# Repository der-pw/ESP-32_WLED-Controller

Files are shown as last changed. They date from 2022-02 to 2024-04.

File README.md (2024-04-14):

# ESP-32_WLED-Controller  

[deutsche Version unten ->](#Deutsch)

### tl;dr
let's talk about [maximum ratings](./maximum_ratings.md)

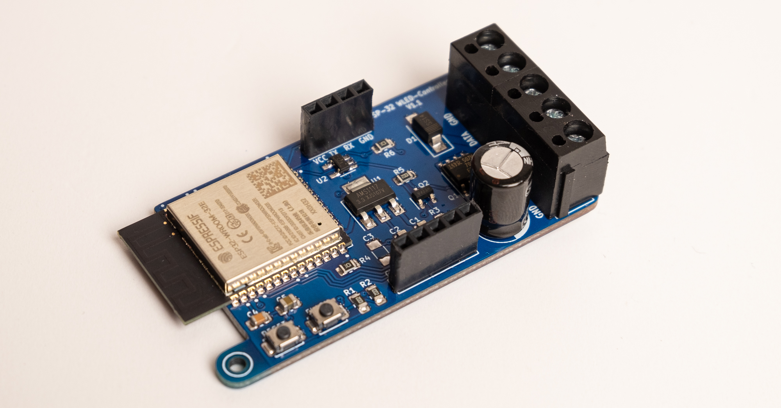
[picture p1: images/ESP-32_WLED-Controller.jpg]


This is like an evolution of my [ESP-12-WLED_Controller](https://github.com/der-pw/ESP-12_WLED-Controller). It based on my ESP-12 Controller, so you can find also all the necessary information about MOSFETs, etc. there as well.

The version with ESP32 is more powerful and enables features like Sound Reactive https://github.com/atuline/WLED with significantly better performance than the ESP2866. Also you can find here the [Sound Reactive Addon](ESP-32_WLED-Controller_Addon) for this controller. The PCB size has just slightly increased, and the controller can still fit into small projects. To have a clean design and ensure the LED strip works with a 5V data level, I used a 74LVC1G125 as a Logic Level Shifter.

Additionally, the power supply for the LED strip can be turned off by using a P-channel MOSFET. Even when turned off, NEOPIXEL strips consume some power (approximately 1mA per pixel). Luckily, WLED provides an option to control a "Relay" through a user-defined pin. I use an IRF7410 (MOSFET P-channel -12 V -16A SO-8) which can switch max 16A. Additional to the P-MOSFET, there is another N-MOSFET. It works as a driver to switch the P-MOSFET with a 5V logic level and also as an inverter, allowing the main MOSFET to logical "active HIGH" at GPIO12 of the ESP.

## Settings
The configuration for inputs and outputs is as follows:

Label | GPIO | Remarks
--- | --- | ---
Data Pin | `GPIO 2`  
Relay Pin | `GPIO12` | **invert**  
*optional:*  
Button 0 | `GPIO32`  
Button 1 | `GPIO33`  
ADC | `GPIO36` | Analog Input

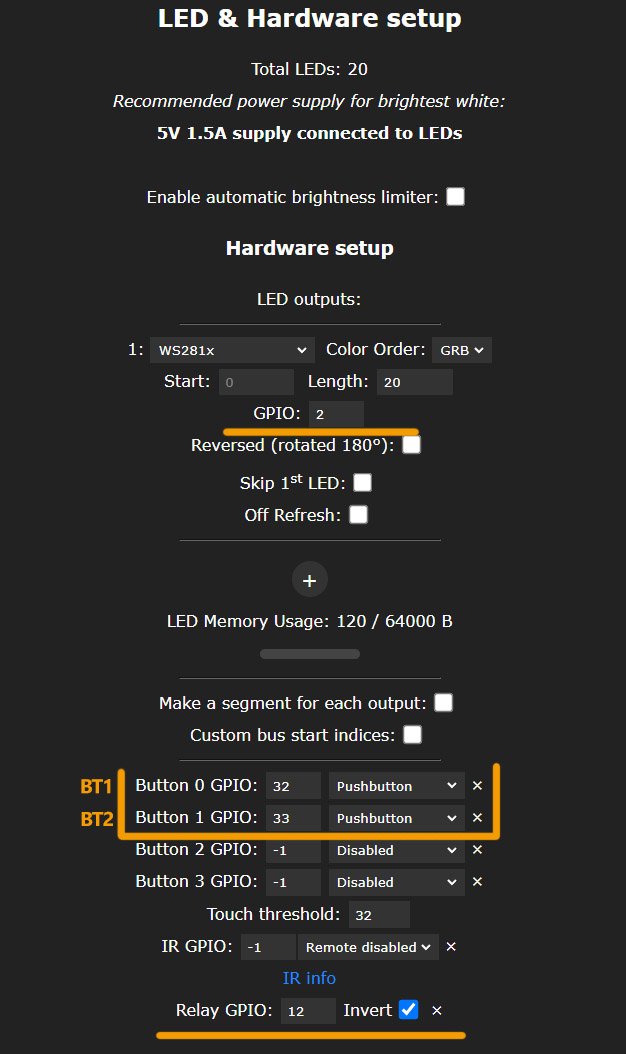
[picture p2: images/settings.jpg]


## Flashing the Firmware
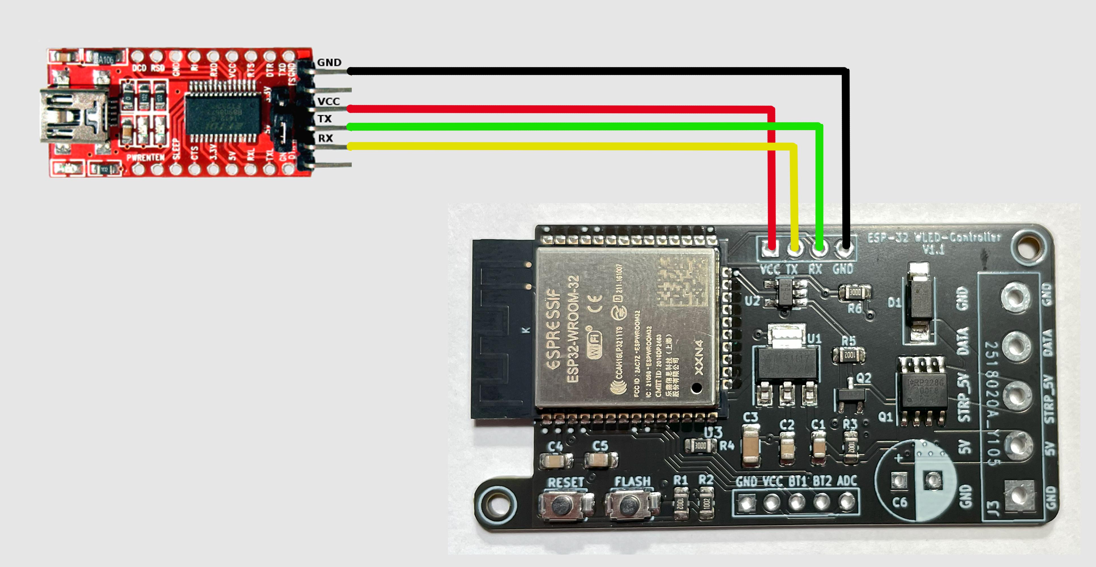
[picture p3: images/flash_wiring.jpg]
Flash Wiring


Connect an FTDI or another compatible UART converter like showing the wiring diagram. Either connect with the FLASH button pressed or, if the controller is already powered by a power supply, hold FLASH, press RESET briefly, and then release FLASH. Now controller is in bootloader mode.

The ESP32 may be underpowered by the FTDI, causing the Brownout Detection is triggered. Therefore, you need to power the controller with an external 5V voltage source.

This controller can be used with a [pre-made binary](https://install.wled.me/).

## Strip and Power Supply
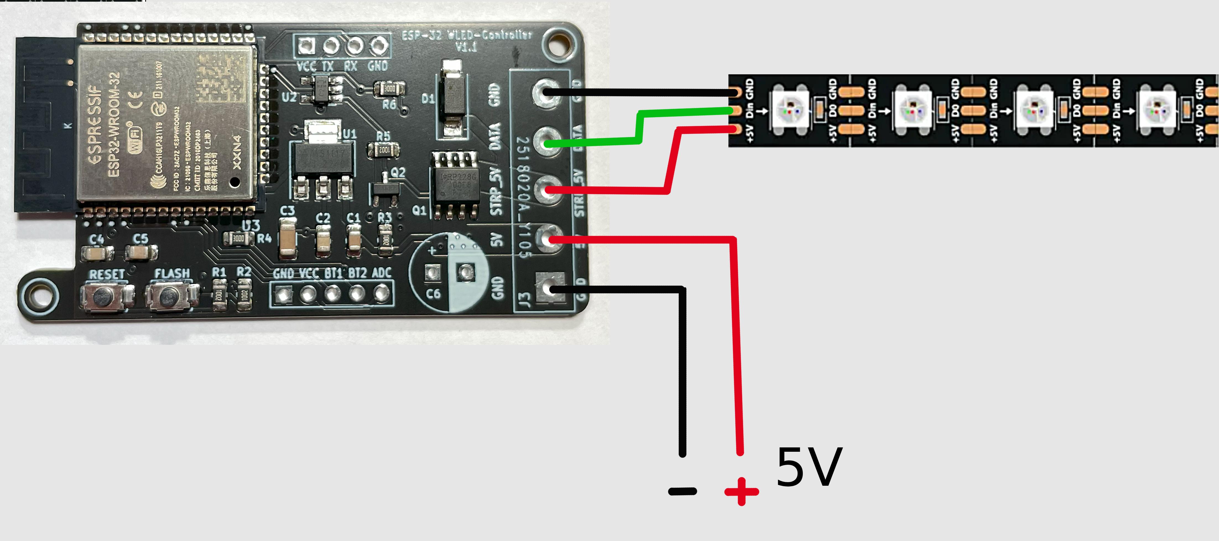
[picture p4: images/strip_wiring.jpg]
Strip and Power Supply


Connect the LED strip and power supply as per the wiring diagram.

## Parts List and BOM
| Designator | Footprint | Quantity | Value | Info |
|---|---|----|----|----|
| C1, C5 | 0805 | 2 | 10µF | |
| C2 | 0805 | 1 | 47µF | |
| C3 | 1206 | 1 | 100µF | |
| C4 | 0805 | 1 | 100nF | |
| D1 | D_SMA_Handsoldering | 1 | Flyback diode| |
| Q1 | SOIC-8_3.9x4.9mm_P1.27mm | 1 | IRF7410 | |
| Q2 | SOT-23 | 1 | IRLML6344 | |
| R1, R2, R3, R5| 0805 | 4 | 10k | |
| R4, R6 | 0805 | 2 | 300R | |
| SW1 | SW_Push_SPST_NO_Alps_SKRK_handsolder | 1 | Reset | |
| SW2 | SW_Push_SPST_NO_Alps_SKRK_handsolder | 1 | Flash | |
| U1 | SOT-223-3_TabPin2 | 1 | AMS1117-3.3  | |
| U2 | SOT-23-5_HandSoldering | 1 | 74LVC1G125 | |
| U3 | ESP32-WROOM-32 | 1 | ESP32-WROOM-32| |

Includes parts that need to be soldered by hand.

Quantity | Description | Info
-------- | -------- | --------
1   | CTB1202-5BK   | [Solderable Screw Terminal - 5-pin, Pitch 5 mm](https://www.reichelt.de/loetbare-schraubklemme-5-pol-rm-5-mm-90--ctb1202-5bk-p292662.html)
1   | NHG-A 1.0M 6.3   | [Capacitor, radial, 1000µF, 6.3V, Pitch 3.5mm](https://www.reichelt.de/elko-radial-1-000-f-6-3v-rm3-5-1000h-105-c-20--nhg-a-1-0m-6-3-p200391.html)

## Case
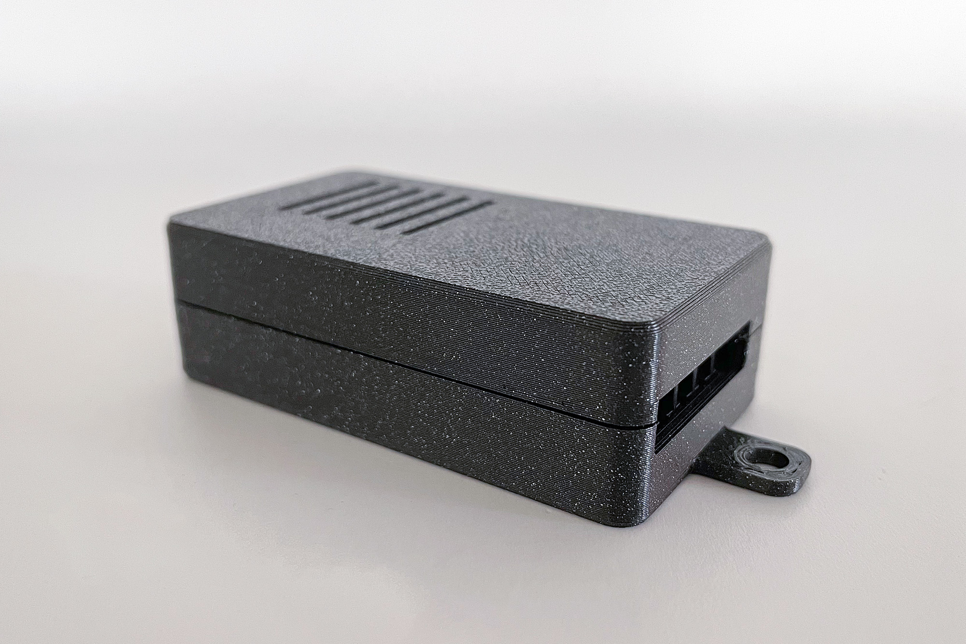
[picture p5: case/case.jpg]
Case
  

There is also a simple case available. Both parts can be connected with a click fastener. The STEP file for modifications to the case is included in the project folder.

## Gerbers
You can find the necessary fabrication data in the “gerber” folder. This also includes the BOM and CPL files. I have had good experiences with JLCPCB, and production there ran smoothly with the data. However, some parts may not always be available.

## Thank You!
A special thanks to [Aircoookie](https://github.com/Aircoookie) and all those involved in the [WLED](https://github.com/Aircoookie/WLED) project!  
Gerber and fabrication data were created using the [Fabrication Toolkit](https://github.com/bennymeg/JLC-Plugin-for-KiCad).



---
## Deutsch
PCB-top_3D-Modell

Dies ist die Weiterentwicklung meines [ESP-12-WLED_Controllers](https://github.com/der-pw/ESP-12_WLED-Controller). Daher kannst du alle nötigen Infos über MOSFET etc. auch dort finden.  
Die Version mit ESP32 ist leistungfähiger und ermöglicht bswp. Sound Reactive Features https://github.com/atuline/WLED. Dafür findes du auch hier ein [Sound Reactive Addon](ESP-32_WLED-Controller_Addon), welches einfach auf den Controller gesteckt werden kann. Die Platinengröße ist nur minimal gewachsen, der Controller lässt sich nach wie vor in kleinen Projekten unterbringen. Für ein sauberes Design und damit der LED-Strip mit einem 5V Datenpegel arbeitet verwende ich einen 74LVC1G125 als Logic Level Shifter.  
Zusätzlich kann die Versorgungsspannung für den LED-Strip über einen P-Kanal MOSFET abgeschaltet werden. Auch im ausgeschalteten Zustand verbrauchen die NEOPIXEL-Strips nämlich Strom (ca. 1mA/Pixel). Ich verwende einen IRF7410 (MOSFET P-Kanal -12 V -16A SO-8) dieser kann max 16A schalten.
Praktischerweise bietet WLED hier die Möglichkeit über einen frei definierten Pin ein "Relay" zu schalten. Vor dem P-MOSFET sitzt ein weiterer N-MOSFET. Einmal funktioniert dieser als Treiber um den P-MOSFET mit 5V Logikpegel zu schalten und zum anderen als Inverter, damit der Haupt-MOSFET praktisch "active HIGH" am GPIO12 des ESP durchschaltet. 

## Einstellungen
Die Konfiguration für Ein-/ und Ausgänge erfolgt wie abgebildet.  

Bezeichnung | GPIO | Bemerkung
--- | --- | ---
Data Pin | `GPIO 2`  
Relay Pin | `GPIO12` | **invert**  
*optional:*  
Button 0 | `GPIO32`  
Button 1 | `GPIO33`  
ADC | `GPIO36` | Analog Eingang

PCB-top_3D-Modell  

## Firmware flashen
Flash Wiring  

FTDI oder anderen passenden UART-Wandler gemäß Anschlussplan verbinden.
Entweder mit gedrücktem FLASH Button verbinden oder wenn der Controller bereits über ein Netzteil versorgt wirden, FLASH gedrückt halten, RESET kurz drücken und danach kann FLASH losgelassen werden.  

Möglicherweise wird der ESP32 vom FTDI unterversorgt und die Brownout Detection reagiert. Daher ist es ratsam, den Controller bereits mit einer externen 5V Spannungsquelle zu versorgen.  

Dieser Controller kann mit einem [fertigen Binary](https://install.wled.me/) verwendet werden.

## Strip und Versorgungsspannung
Strip and Power Supply  
LED Strip und Netzteil werden gemäß Anschlussplan verbunden.

## Teileliste und BOM
| Designator | Footprint | Quantity | Value | Info |
|---|---|----|----|----|
| C1, C5 | 0805 | 2 | 10µF | |
| C2 | 0805 | 1 | 47µF | |
| C3 | 1206 | 1 | 100µF | |
| C4 | 0805 | 1 | 100nF | |
| D1 | D_SMA_Handsoldering | 1 | Flyback diode| |
| Q1 | SOIC-8_3.9x4.9mm_P1.27mm | 1 | IRF7410 | |
| Q2 | SOT-23 | 1 | IRLML6344 | |
| R1, R2, R3, R5| 0805 | 4 | 10k | |
| R4, R6 | 0805 | 2 | 300R | |
| SW1 | SW_Push_SPST_NO_Alps_SKRK_handsolder | 1 | Reset | |
| SW2 | SW_Push_SPST_NO_Alps_SKRK_handsolder | 1 | Flash | |
| U1 | SOT-223-3_TabPin2 | 1 | AMS1117-3.3  | |
| U2 | SOT-23-5_HandSoldering | 1 | 74LVC1G125 | |
| U3 | ESP32-WROOM-32 | 1 | ESP32-WROOM-32| |

Beinhaltet Teile, die von Hand eingelötet werden müssen.
Anzahl | Beschreibung | Info
-------- | -------- | --------
1   | CTB1202-5BK   | [Lötbare Schraubklemme - 5-pol, RM 5 mm](https://www.reichelt.de/loetbare-schraubklemme-5-pol-rm-5-mm-90--ctb1202-5bk-p292662.html)
1   | NHG-A 1,0M 6,3   | [Elko, radial, 1.000µF, 6,3V, RM3,5](https://www.reichelt.de/elko-radial-1-000-f-6-3v-rm3-5-1000h-105-c-20--nhg-a-1-0m-6-3-p200391.html)

## Gehäuse
Gehäuse  

Ein einfaches Gehäuse gibt es auch.
Beide Teile können über einen Klickverschluss miteinander verbunden werden.
Für Änderungen am Gehäuse liegt im Projektorder die STEP-Datei.  

## Gerberdaten
Du kann die nötigen Fertigungsdaten im Ordner "gerber" finden. Darin enthalten sind auch die BOM und CPL Files. Mit JLCPCB habe ich guter Erfahrungen gemacht, und mit den Daten lief die Fertigung dort auch problemlos. Es ist jedoch möglich, das manche Teile vielleicht nicht immer verfügbar sind.

## Dankeschön!  
Ganz besonderer Dank geht an [Aircoookie](https://github.com/Aircoookie) und alle Beteiligten, die am [WLED](https://github.com/Aircoookie/WLED) Projekt mitarbeiten!  
Gerber und Fertigungsdaten wurden mit [Fabrication Toolkit](https://github.com/bennymeg/JLC-Plugin-for-KiCad) erstellt!



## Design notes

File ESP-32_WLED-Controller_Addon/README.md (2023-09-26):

# ESP-32_WLED-Controller_addon  

[deutsche Version unten ->](#Deutsch)

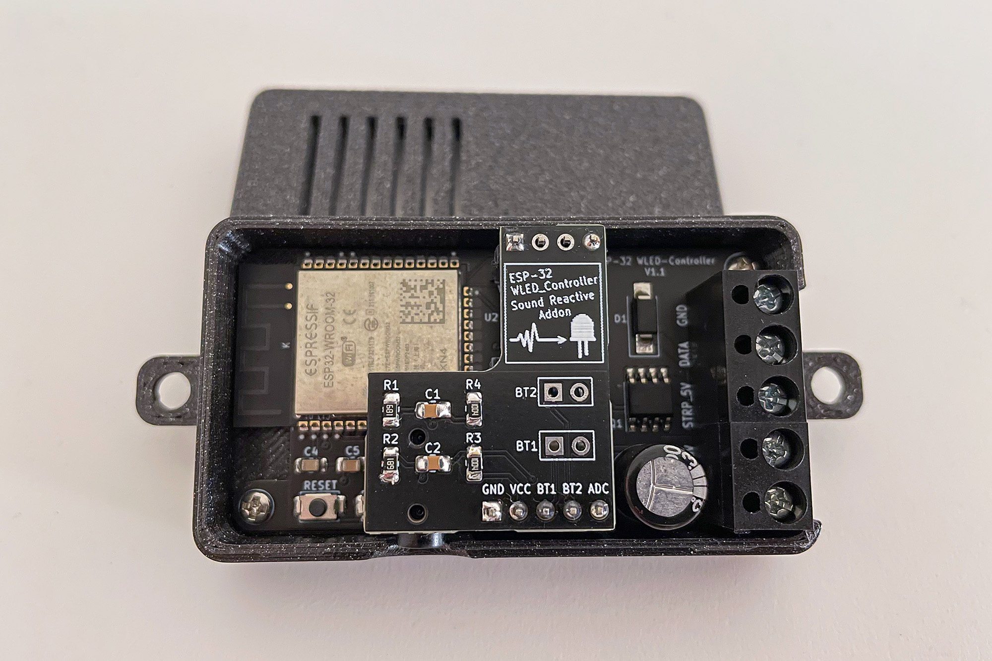
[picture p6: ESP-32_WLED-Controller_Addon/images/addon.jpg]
PCB-top_addon


This addon board allows you to expand the ESP-32_WLED-Controller with the Sound Reactive feature https://github.com/atuline/WLED. The board is practically stacked on top of the controller using 2.54mm pin and socket headers.

## Settings
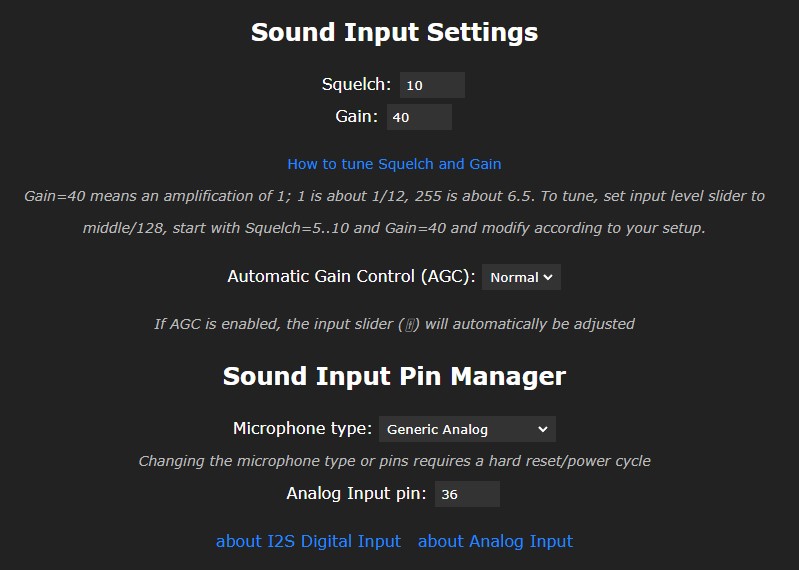
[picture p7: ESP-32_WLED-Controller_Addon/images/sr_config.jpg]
Settings


WLED Sound Reactive comes with an additional configuration menu.
For Squelch and Gain, you'll need to configure your own settings.
Microphone type is **Generic Analog**.
The Analog Input Pin is on `GPIO36`.

## Case
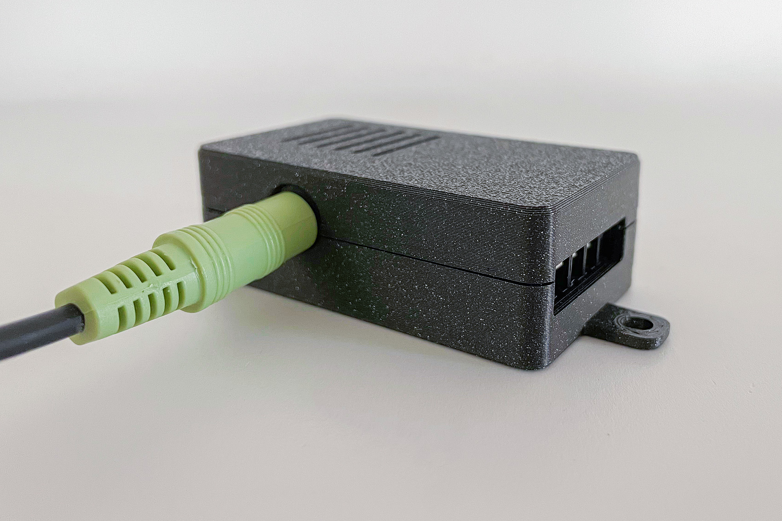
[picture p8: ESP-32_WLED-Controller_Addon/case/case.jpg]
case


There is also a simple case available for connecting the 3.5mm audio jack.
The STEP file for further modifications is also located in the "case" folder.

## BOM

| Refs | Qty | Component | Description |
| --- | --- | --- | --- |
| R1, R2 | 2 | 680R | Resistor 0805  |
| R3, R4 | 2 | 1M | Resistor 0805  |
| C1, C2 | 2 | 100nF | Capacitor 0805  |
| J3 | 1 | Audio Jack 3.5mm | PJ230D https://de.aliexpress.com/item/4000661908135.html |
| J1 | 1 | PinHeader_1x05_P2.54mm_Vertical |
| J5 | 1 | PinHeader_1x04_P2.54mm_Vertical |

## Gerber Data

You can find the manufacturing data for the board in the “gerber” folder.
In addition, there is also the BOM and CPL data for SMT production. However, the assembly is two-sided, as the jack socket is mounted on the bottom for space reasons.
The jack socket is called PJ230D. I found these cheaply at https://de.aliexpress.com/item/4000661908135.html.

---
## Deutsch

PCB-top_addon

Mit dieser Addon-Platine lässt sich der ESP-32_WLED-Controller um das Sound Reactive Feature erweitern https://github.com/atuline/WLED. Die Platine wird praktisch im "Huckepack" auf den Controller gesteckt.
Dazu lassen sich 2.54mm Stift- und Buchsenleisten verwenden.

## Einstellungen
Einstellungen

WLED Soundreactive hat ein weiteres Konfigurationsmenü.
Für Squelch und Gain muss man seine eigenen Einstellungen fingen.
Micropone type ist **Generic Analog**.  
Der Analog Input Pin liegt auf `GPIO36`.

## Gehäuse
case

Es gibt auch ein einfaches Gehäuse, damit man den 3,5mm Klinkenstecker anschließen kann.
Die STEP-Datei für weitere Modifikationen befindet sich auch in dem Ordner "case" 

## BOM

| Refs | Qty | Component | Description |
| --- | --- | --- | --- |
| R1, R2 | 2 | 680R | Resistor 0805  |
| R3, R4 | 2 | 1M | Resistor 0805  |
| C1, C2 | 2 | 100nF | Capacitor 0805  |
| J3 | 1 | Audio Jack 3.5mm | PJ230D https://de.aliexpress.com/item/4000661908135.html |
| J1 | 1 | PinHeader_1x05_P2.54mm_Vertical |
| J5 | 1 | PinHeader_1x04_P2.54mm_Vertical |

## Gerberdaten

Die Fertigungsdaten zur Platine findest du im Ordner "gerber". 
Zusätzlich gibt es dort auch die BOM und CPL Daten für die SMT-Fetigung. Die Bestückung ist allerdings zweiseitig, da aus Platzgründen die Klinkenbuchse auf der Unterseite montiert wird.
Die Klinkenbuchse heißt PJ230D. Diese habe ich günstig unter https://de.aliexpress.com/item/4000661908135.html gefunden.

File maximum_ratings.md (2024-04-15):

## Maximum Ratings

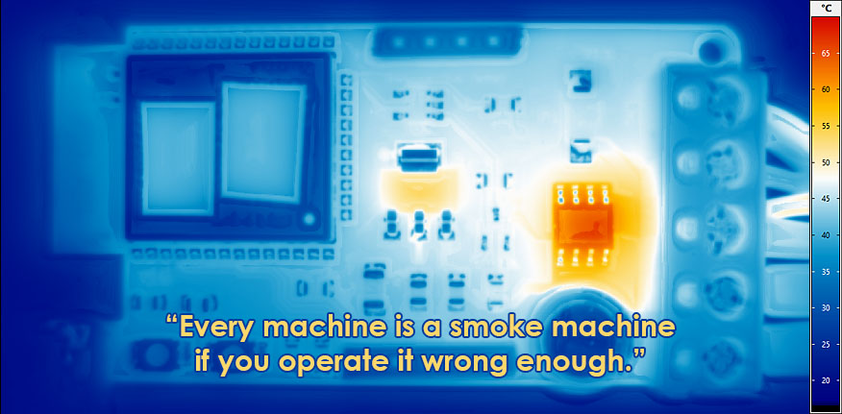
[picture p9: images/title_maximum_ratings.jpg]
IR-Capture
  

I did a few tests to check how much power the board can operate with.  
After I parked the board and components in the heated 50°C 3D printer housing for about 2 hours, I set the emissivity for the PCB surface and the components (AMS1117 and IRF4710) to near 0.95. This corresponded very well with my reference values from the insulating tape and Kapton tape, which was stuck to the shield to measure the temperature of the ESP housing.
I've tested with about 6m WS2812B Strip with 375Pixels. Connected on booth sides.
The Current was measured with a KAIWEETS HT206D clamp meter in good condition.  
Thermal images were made with an Infratec Vario Cam HD, 30mm Lens.

## Front Side
"M-Wert" is average of the area. But it's also the value for one point. I forgot to switch the language. 

### 5 Ampere
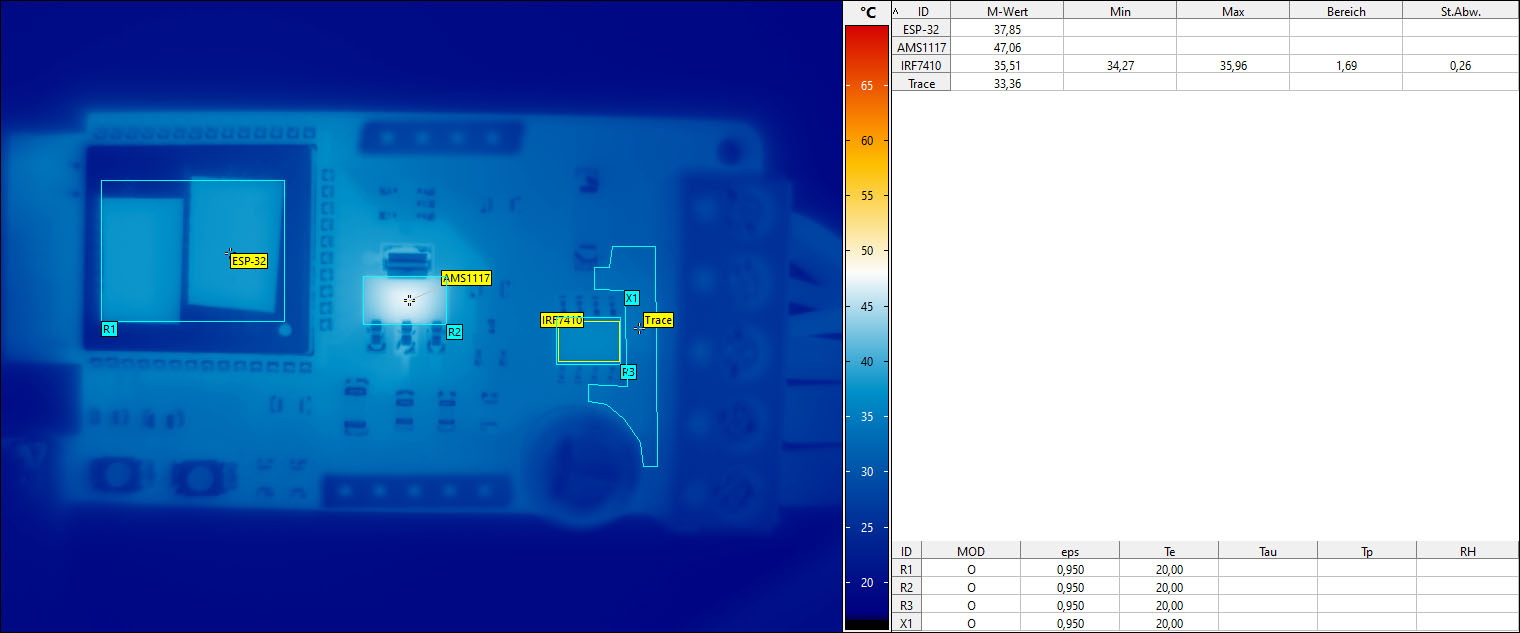
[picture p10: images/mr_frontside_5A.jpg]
Front 5A
  
MOSFET is almost still cold.

### 7.5 Ampere
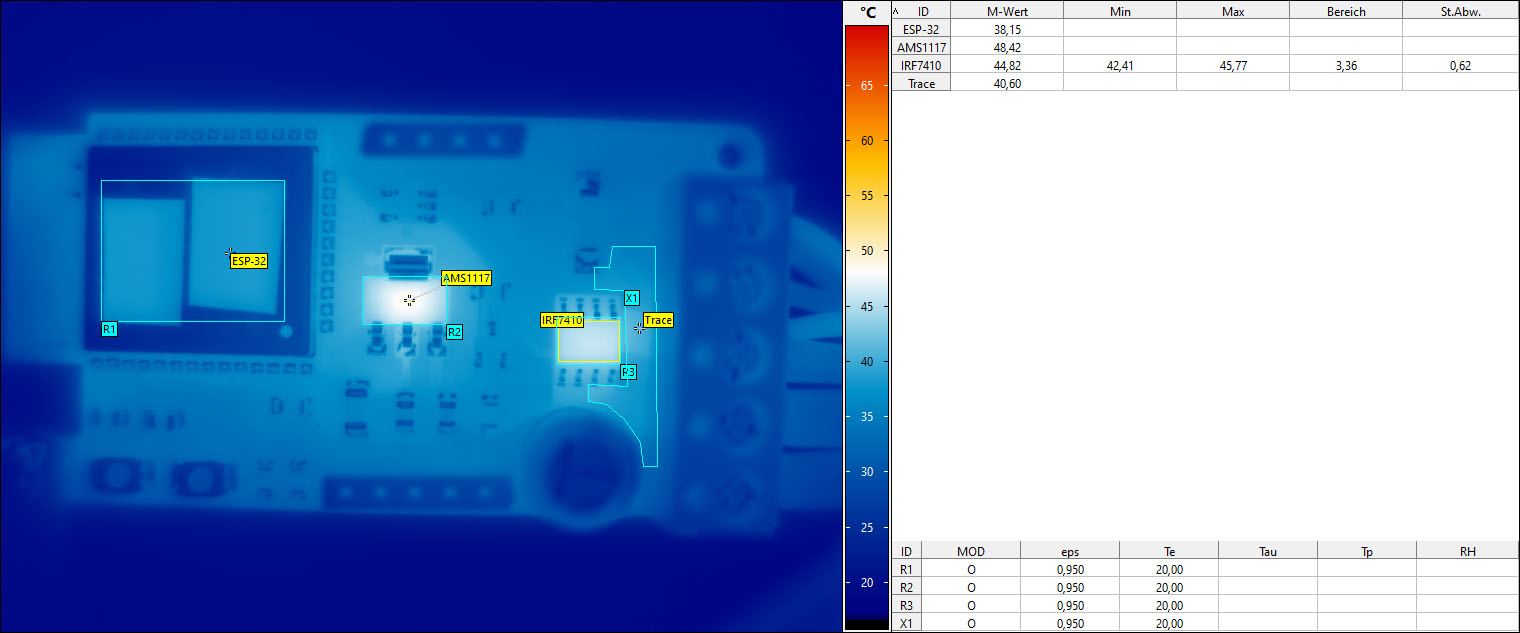
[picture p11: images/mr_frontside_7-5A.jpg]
Front 7.5A
  
MOSFET completely uncritical at 45°C, the trace at 40°C. Hold time in this state was 30 minutes.

### 10 Ampere
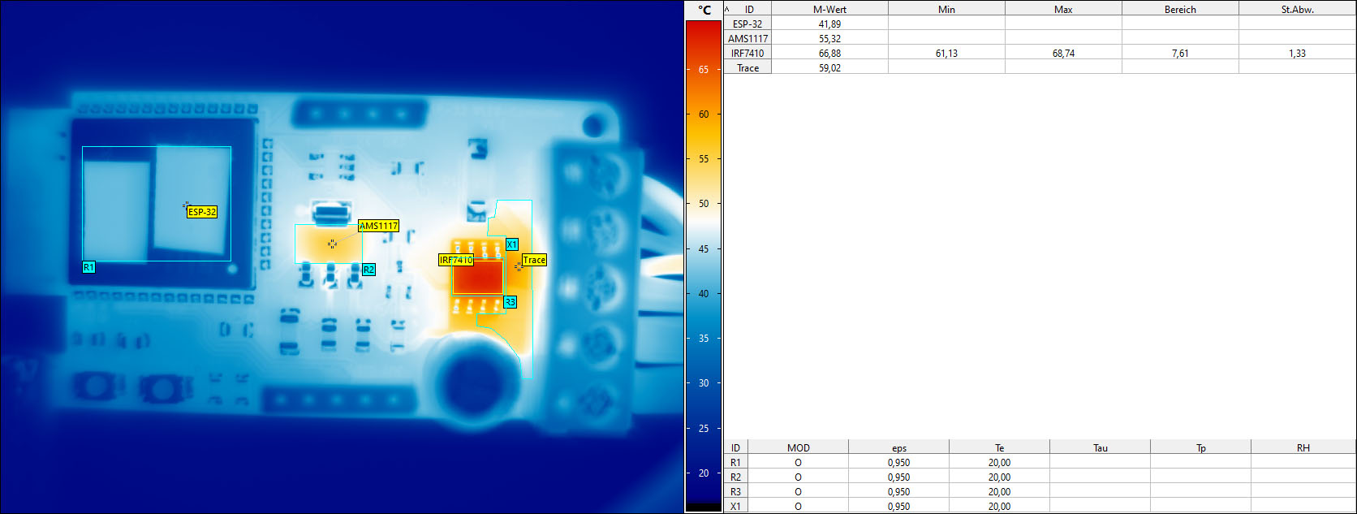
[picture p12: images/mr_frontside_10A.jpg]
Front 10A
  
MOSFET housing was at almost 70°C, the trace scratched at the 60°C mark.
Not super critical, but this is where I would start thinking about how to start cooling.
Accumulated heat should be avoided in the housing or even actively removed.

## Back Side
### 5 Ampere
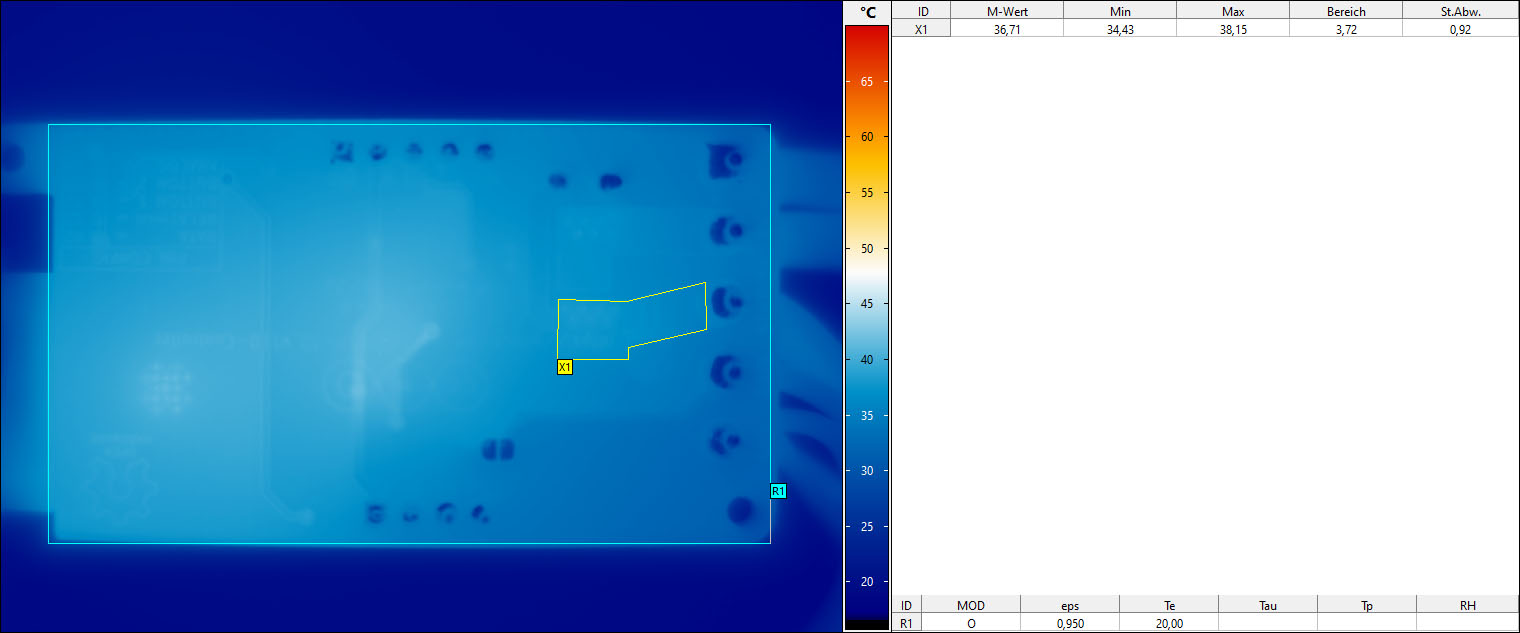
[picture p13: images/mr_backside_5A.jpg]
Back 5A
 

### 10 Ampere
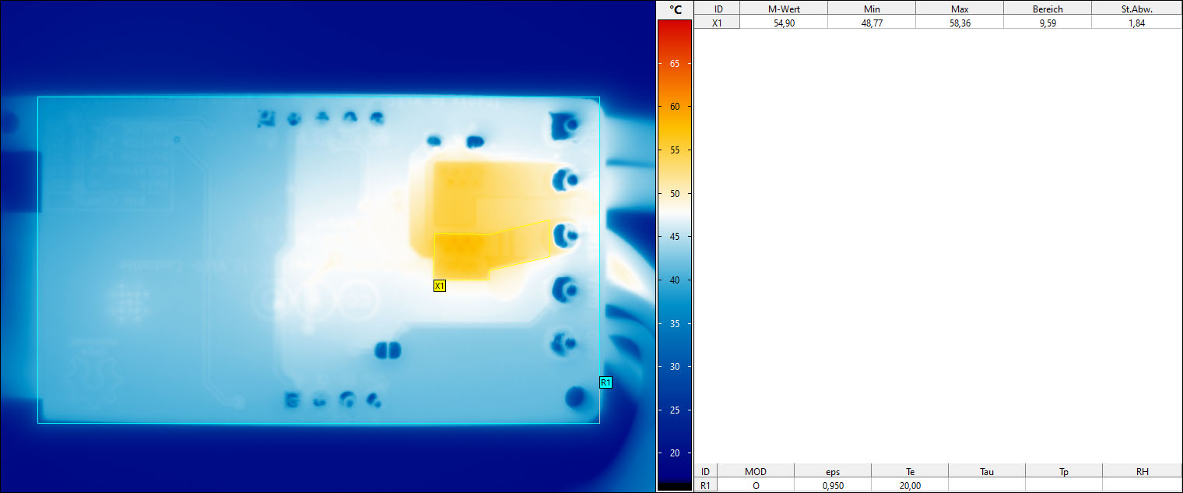
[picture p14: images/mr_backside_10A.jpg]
Back 10A
 

## Summary
I think the board is not suitable for the very, very large projects. At least not if you want to chase all the current through the MOSFET. Of course you can also switch an external relay via "STRP_5V". If I had to answer the question of how long the strip can be, I would say. maximum 3m to 4m with 60LED/m. That's a good value.  
In this case, shorter is better. 😁  
It's often the case that you never set the full brightness, but remember that may errors can occur. You just have to decide that for yourself. I hope the metrics will help you.

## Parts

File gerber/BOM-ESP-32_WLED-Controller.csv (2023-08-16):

Comment | Designator | Footprint | LCSC
IRF7410 | Q1 | SOIC-8_3.9x4.9mm_P1.27mm | C148144
100µF | C3 | C_1206_3216Metric_Pad1.33x1.80mm_HandSolder | C15008
10µF | C1,C5 | C_0805_2012Metric_Pad1.18x1.45mm_HandSolder | C15850
47µF | C2 | C_0805_2012Metric_Pad1.18x1.45mm_HandSolder | C16780
10k | R1,R2,R3,R5 | R_0805_2012Metric_Pad1.20x1.40mm_HandSolder | C17414
300R | R4,R6 | R_0805_2012Metric_Pad1.20x1.40mm_HandSolder | C17617
74LVC1G125 | U2 | SOT-23-5_HandSoldering | C23654
Flyback diode | D1 | D_SMA_Handsoldering | C2480
100nF | C4 | C_0805_2012Metric_Pad1.18x1.45mm_HandSolder | C49678
IRLML6344 | Q2 | SOT-23 | C53550
AMS1117-3.3 | U1 | SOT-223-3_TabPin2 | C6186
ESP32-WROOM-32 | U3 | ESP32-WROOM-32 | C82899
Reset | SW1,SW2 | SW_Push_SPST_NO_Alps_SKRK_handsolder | C843669

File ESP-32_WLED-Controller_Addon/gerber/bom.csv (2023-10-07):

Designator | Footprint | Quantity | Value | LCSC Part #
C1, C2 | 0805 | 2 | 100nF | C49678
J3 | Jack_3.5mm_PJ320D_Horizontal | 1 | AudioJack4
R1, R2 | 0805 | 2 | 680R | C17798
R3, R4 | 0805 | 2 | 1M | C17514

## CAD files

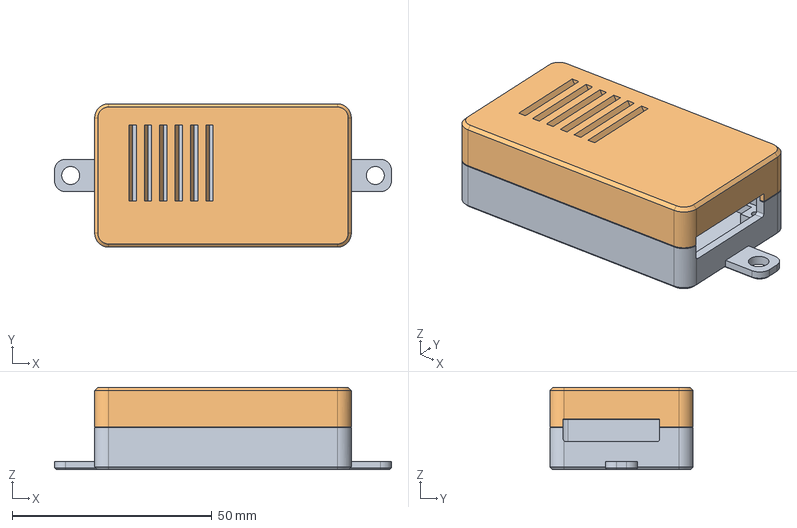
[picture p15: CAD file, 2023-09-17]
case/ESP-32_WLED-Controller.step
84.3 x 35.9 x 20.5 mm

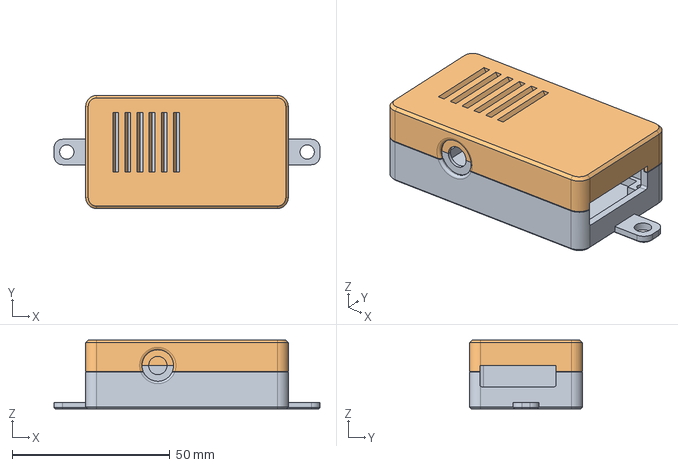
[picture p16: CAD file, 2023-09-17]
ESP-32_WLED-Controller_Addon/case/ESP-32_WLED-Controller_SR.step
84.3 x 35.9 x 21.8 mm

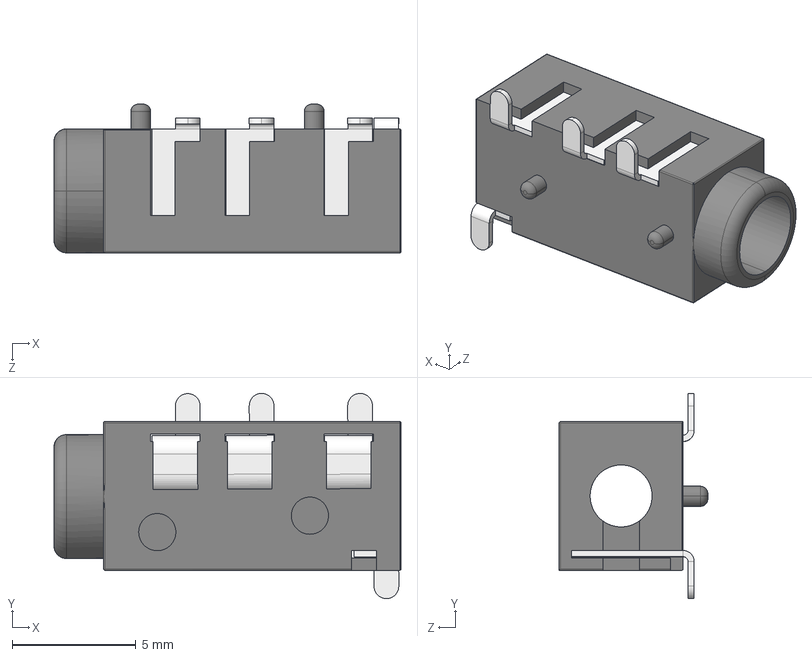
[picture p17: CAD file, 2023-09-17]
ESP-32_WLED-Controller_Addon/KiCad7_Project/PJ320D/PJ320D.STEP
14.0 x 8.28 x 6.00 mm
PJ320A
PJ320D-Pin x 3
PJ320D-Pin-B

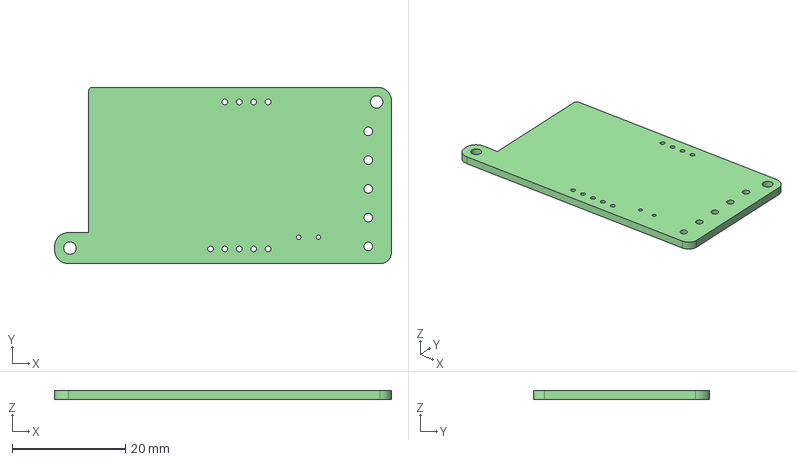
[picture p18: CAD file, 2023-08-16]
KiCad7_Project/ESP-32_WLED-Controller.step
59.5 x 31.2 x 1.60 mm

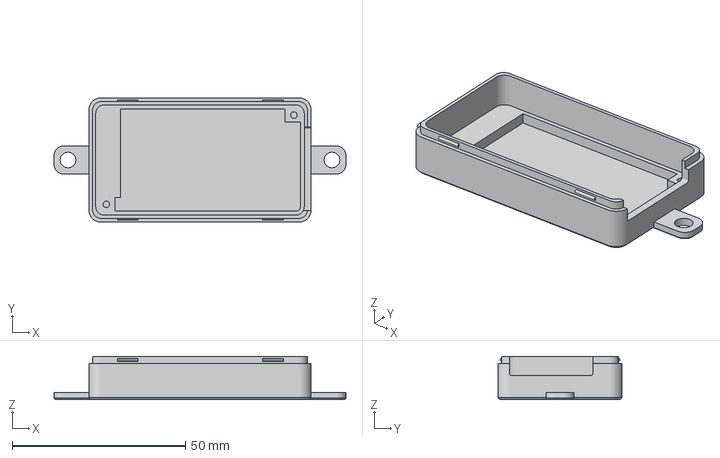
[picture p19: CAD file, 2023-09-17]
case/ESP-32_WLED-Controller_bottom.3mf
84.3 x 35.9 x 12.5 mm

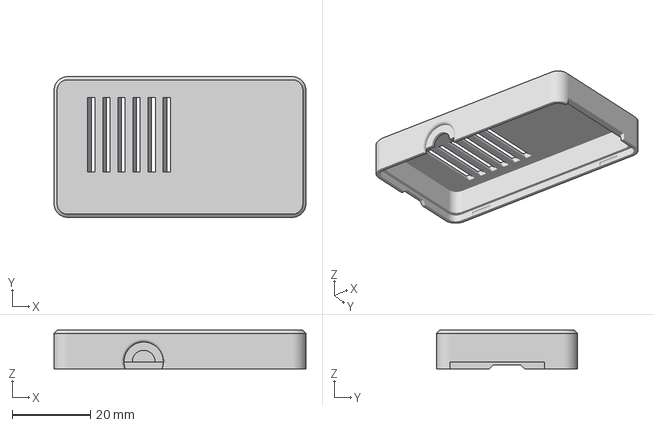
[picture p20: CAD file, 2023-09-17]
ESP-32_WLED-Controller_Addon/case/ESP-32_WLED-Controller_SR_top.3mf
64.2 x 35.9 x 9.85 mm

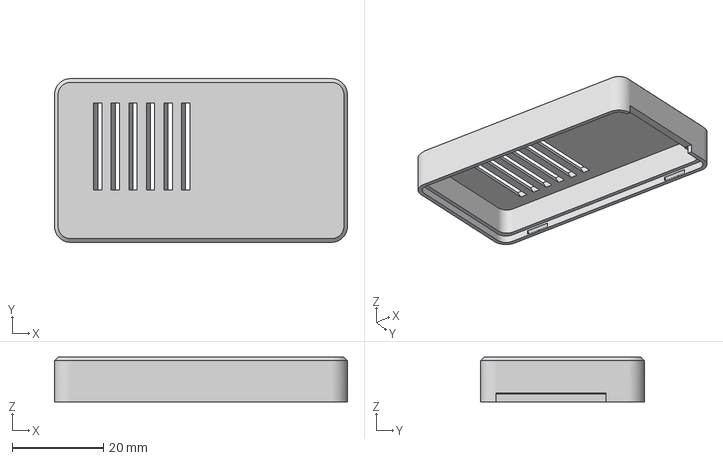
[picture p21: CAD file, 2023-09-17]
case/ESP-32_WLED-Controller_top.3mf
64.2 x 35.9 x 9.85 mm

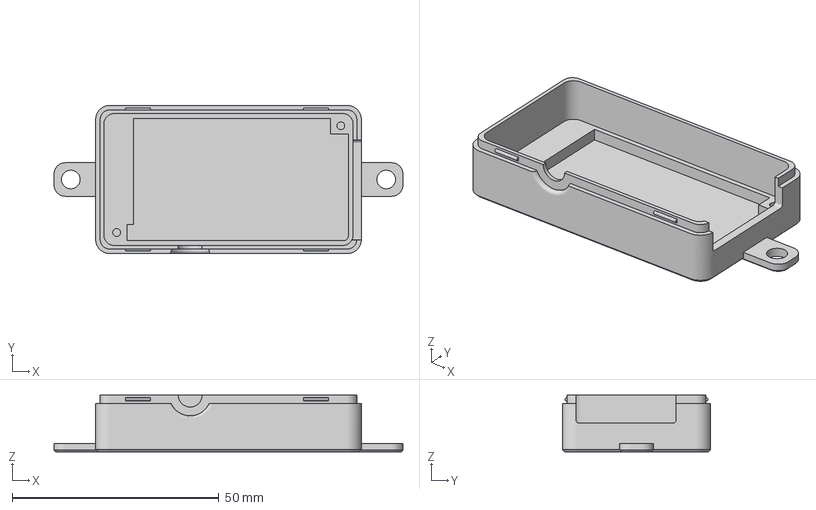
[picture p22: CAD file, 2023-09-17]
ESP-32_WLED-Controller_Addon/case/ESP-32_WLED-Controller_SR_bottom.3mf
84.3 x 35.9 x 13.7 mm

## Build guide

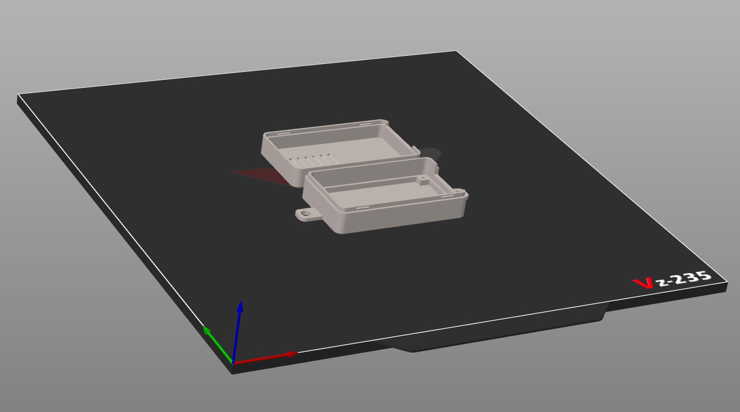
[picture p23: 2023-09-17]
case/print_direction.jpg

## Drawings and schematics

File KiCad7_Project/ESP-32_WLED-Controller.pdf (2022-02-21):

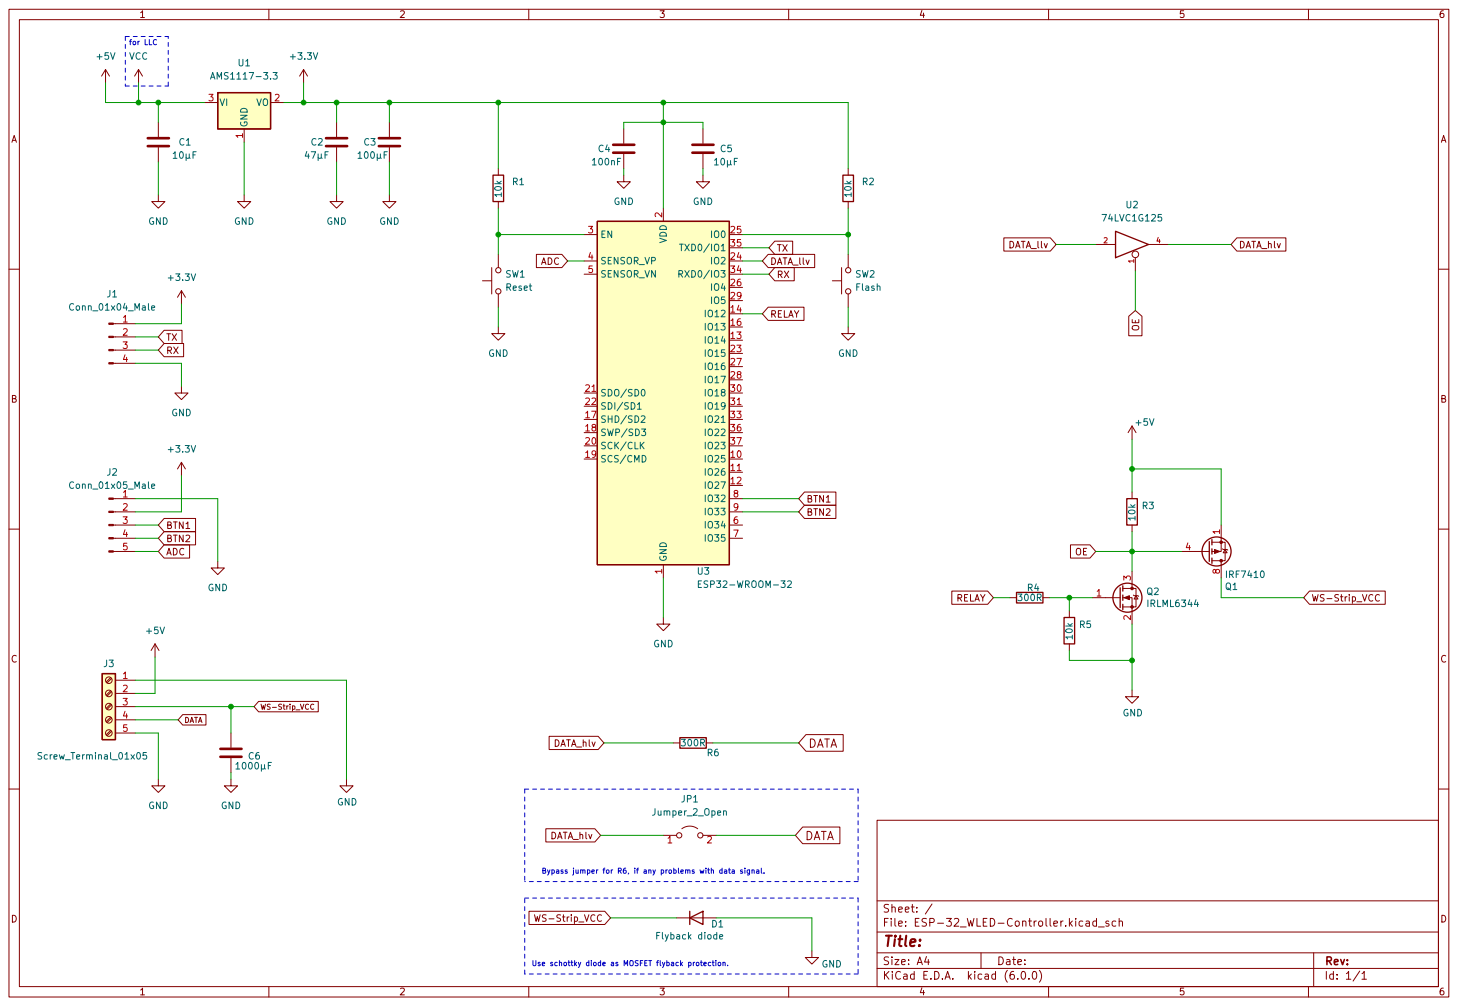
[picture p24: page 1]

2 SCK/CLK 20 SDO/SD0 21 SDI/SD1 22

Bypass jumper for R6, if any problems with data signal. Use schottky diode as MOSFET flyback protection.

File: ESP-32_WLED-Controller.kicad_sch Sheet: / GND

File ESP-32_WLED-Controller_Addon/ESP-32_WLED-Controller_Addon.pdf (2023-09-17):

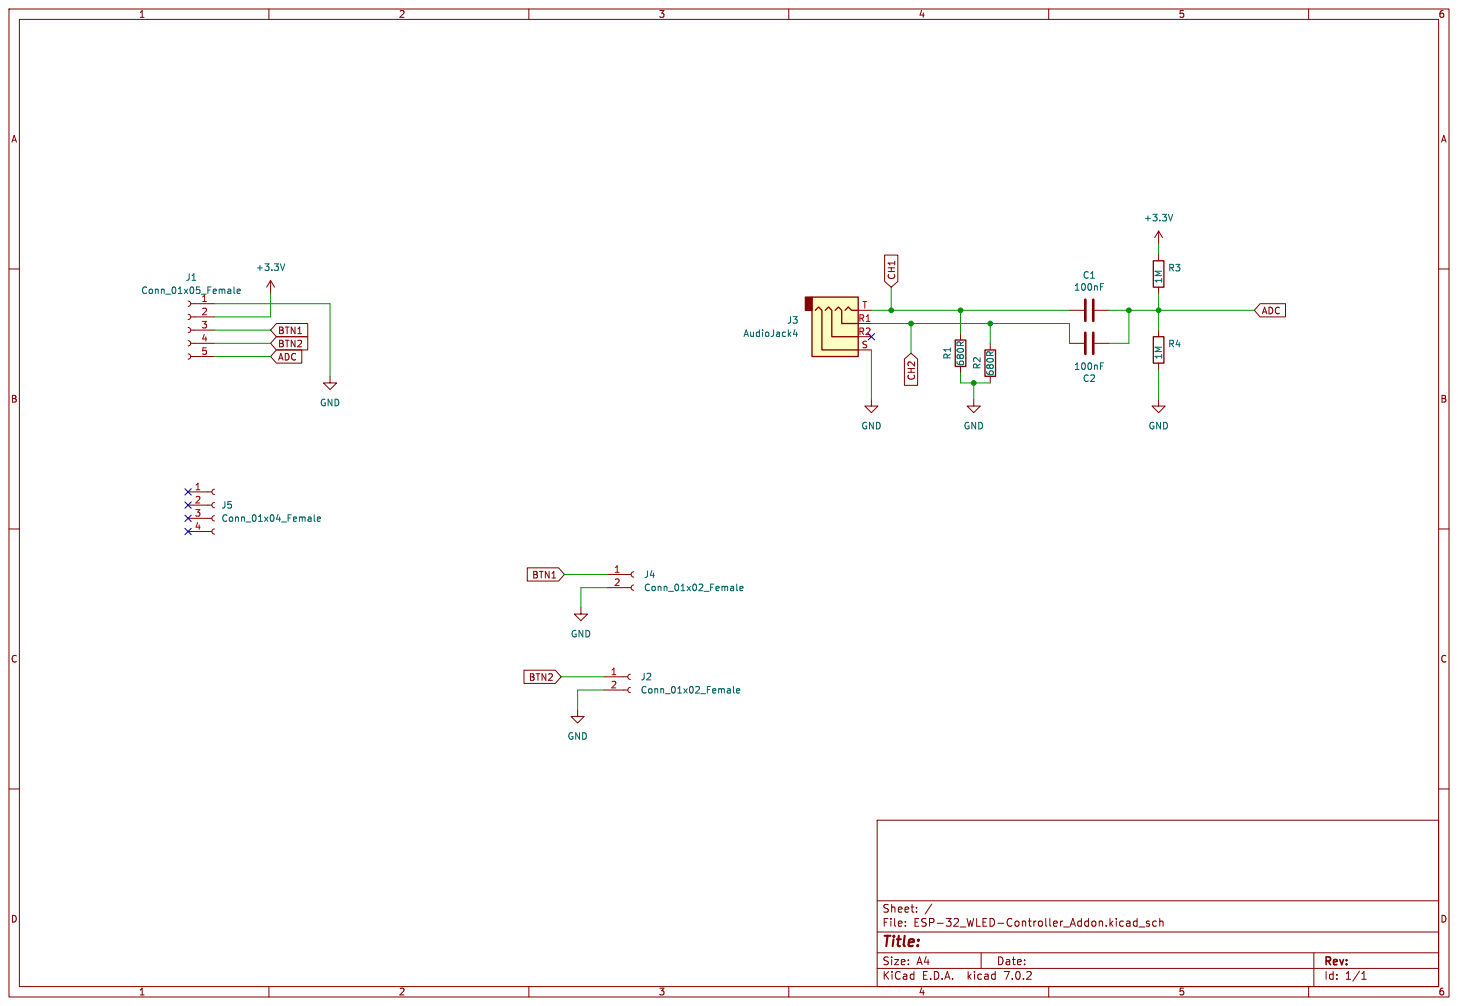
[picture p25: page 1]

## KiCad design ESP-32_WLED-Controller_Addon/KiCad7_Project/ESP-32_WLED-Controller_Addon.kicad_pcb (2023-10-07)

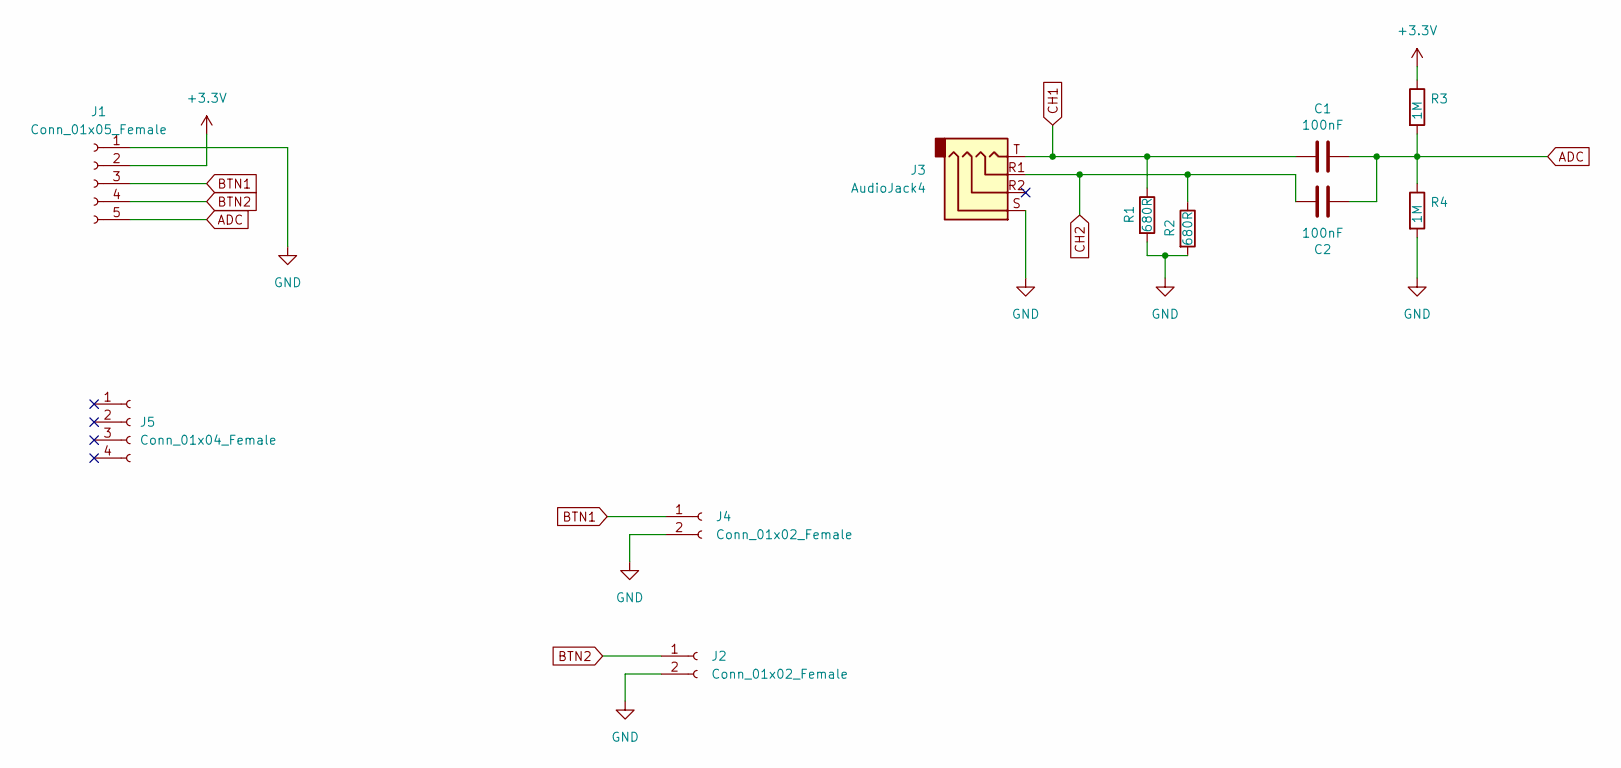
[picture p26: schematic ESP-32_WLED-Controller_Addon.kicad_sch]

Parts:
C1, C2: 100nF; C_0805_2012Metric_Pad1.18x1.45mm_HandSolder; LCSC C49678
J1: Conn_01x05_Female; PinHeader_1x05_P2.54mm_Vertical
J2, J4: Conn_01x02_Female; PinHeader_1x02_P2.54mm_Vertical
J3: AudioJack4; Jack_3.5mm_PJ320D_Horizontal
J5: Conn_01x04_Female; PinHeader_1x04_P2.54mm_Vertical
R1, R2: 680R; R_0805_2012Metric_Pad1.20x1.40mm_HandSolder; LCSC C17798
R3, R4: 1M; R_0805_2012Metric_Pad1.20x1.40mm_HandSolder; LCSC C17514

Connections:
+3V3: J1.2, R3.1
ADC: C1.2, C2.1, J1.5, R3.2, R4.1
BTN1: J1.3, J4.1
BTN2: J1.4, J2.1
CH1: C1.1, J3.T, R1.1
CH2: C2.2, J3.R1, R2.1
GND: J1.1, J2.2, J3.S, J4.2, R1.2, R2.2, R4.2

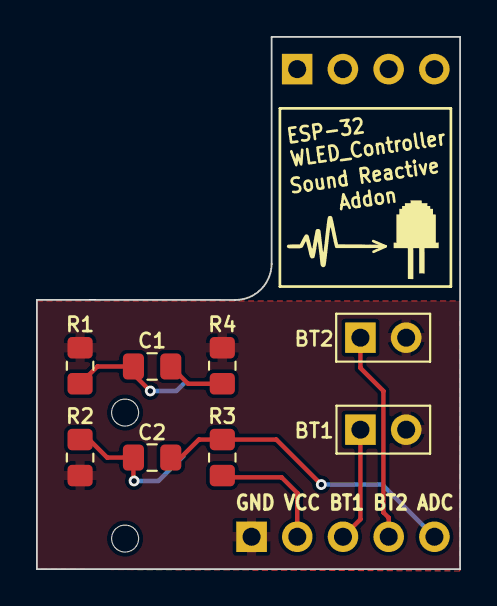
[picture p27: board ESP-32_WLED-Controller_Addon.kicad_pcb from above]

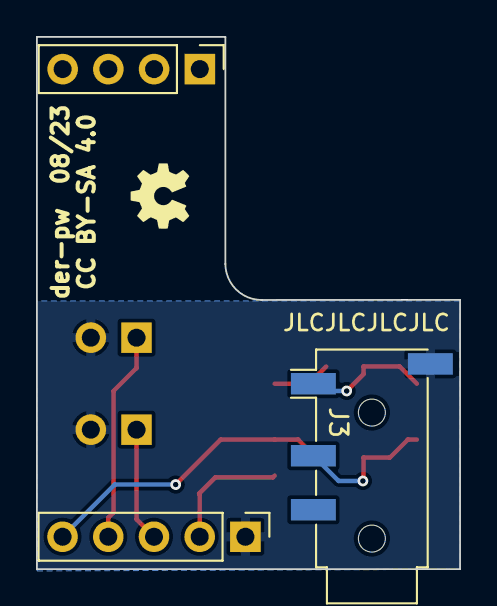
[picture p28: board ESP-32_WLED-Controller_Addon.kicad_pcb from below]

Board: 2 copper layers, 23.5 x 29.6 mm, 11 parts (3 on the bottom side), 7 nets.

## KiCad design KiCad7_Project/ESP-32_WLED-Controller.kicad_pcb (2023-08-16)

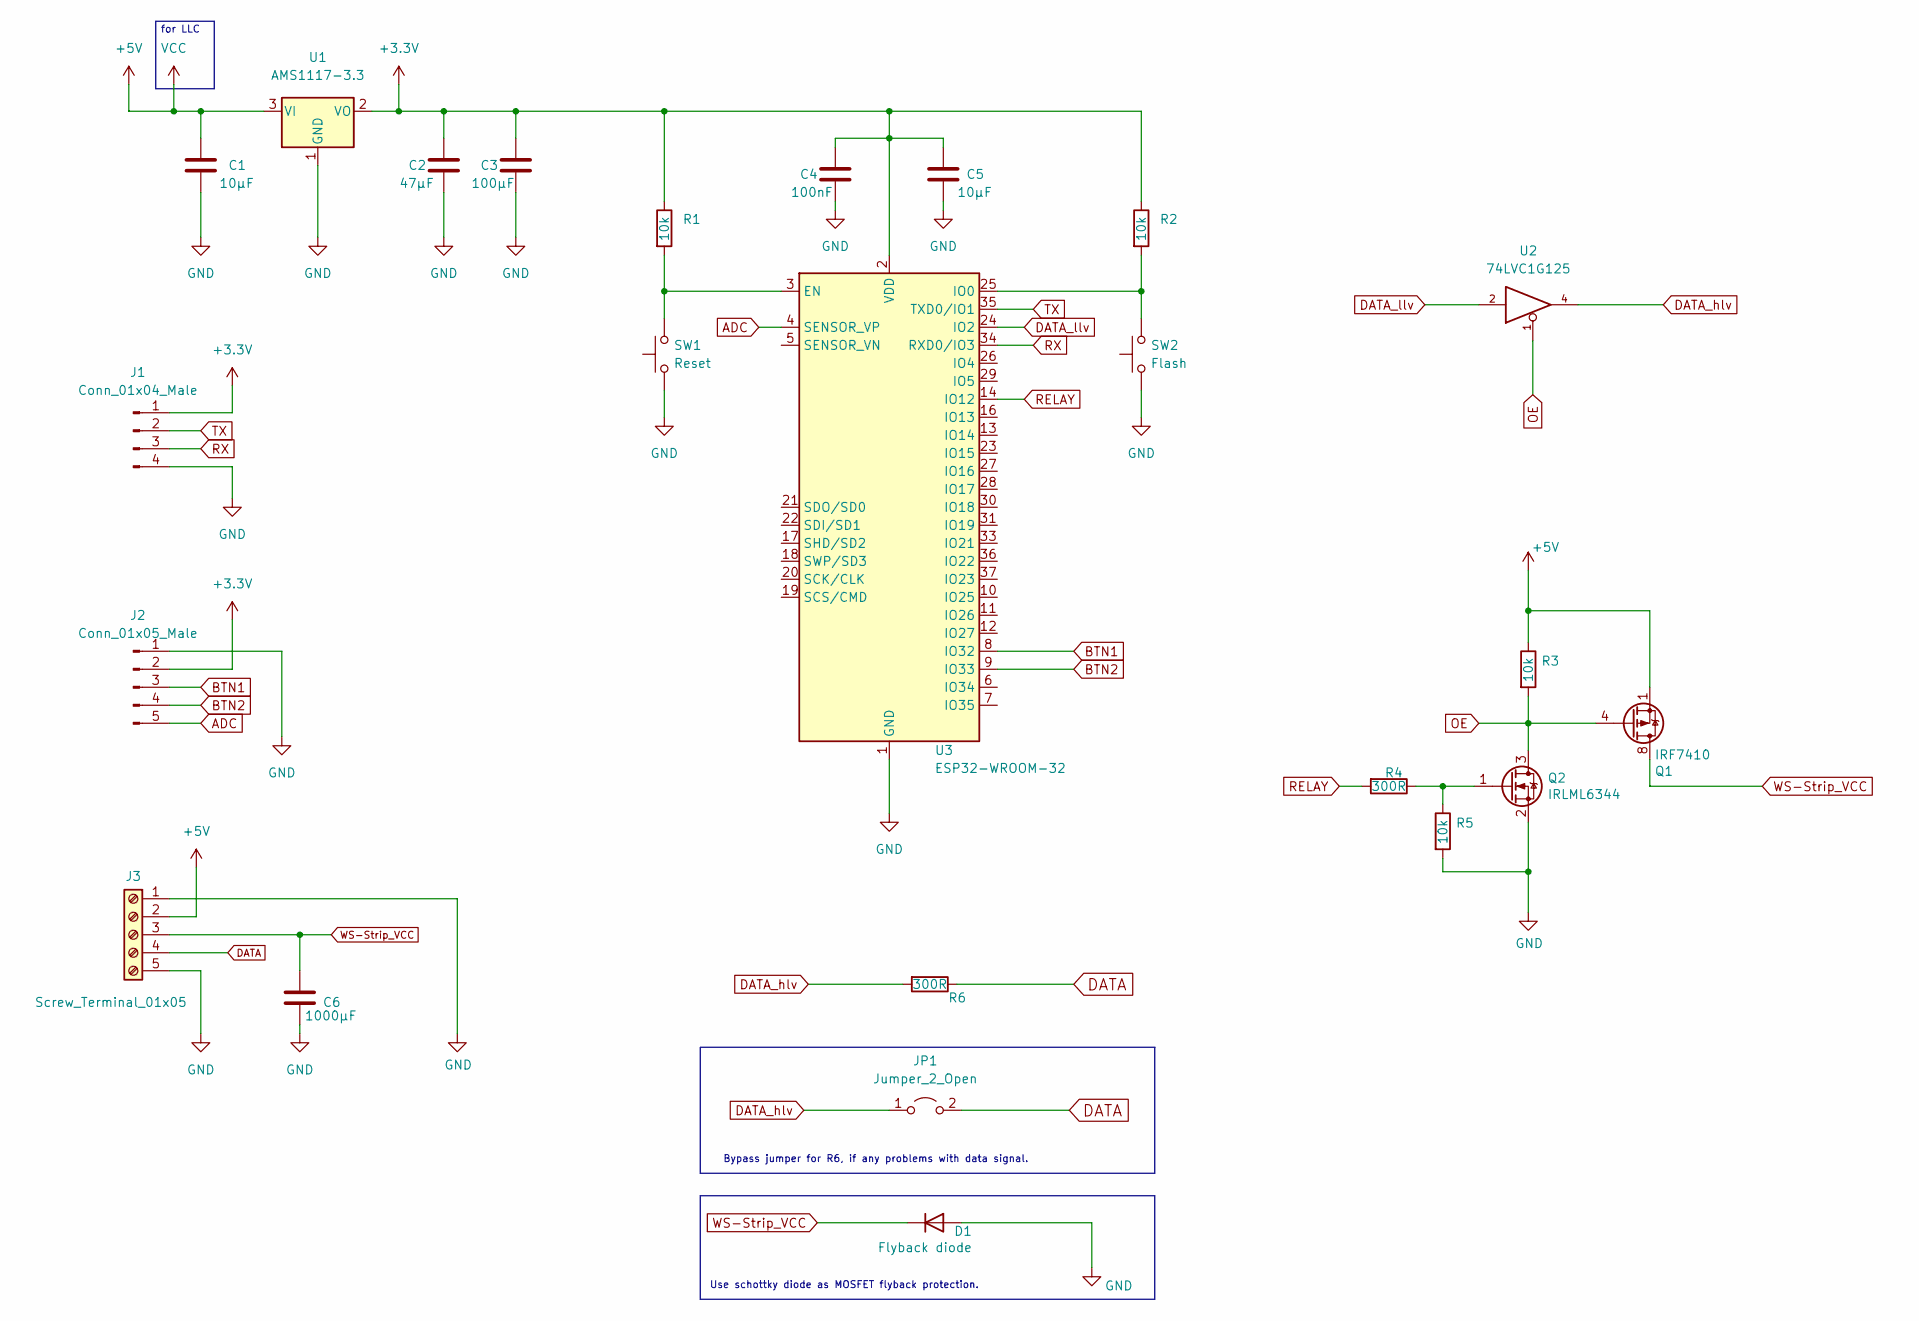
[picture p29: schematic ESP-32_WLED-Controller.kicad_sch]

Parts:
C1, C5: 10µF; C_0805_2012Metric_Pad1.18x1.45mm_HandSolder; LCSC C15850
C2: 47µF; C_0805_2012Metric_Pad1.18x1.45mm_HandSolder; LCSC C16780
C3: 100µF; C_1206_3216Metric_Pad1.33x1.80mm_HandSolder; LCSC C15008
C4: 100nF; C_0805_2012Metric_Pad1.18x1.45mm_HandSolder; LCSC C49678
C6: 1000µF; CP_Radial_D8.0mm_P3.50mm; LCSC C189254
D1: Flyback diode; D_SMA_Handsoldering; LCSC C2480
J1: Conn_01x04_Male; PinSocket_1x04_P2.54mm_Vertical
J2: Conn_01x05_Male; PinSocket_1x05_P2.54mm_Vertical
J3: Screw_Terminal_01x05; TerminalBlock_bornier-5_P5.08mm
JP1: Jumper_2_Open; SolderJumper-2_P1.3mm_Open_RoundedPad1.0x1.5mm
Q1: IRF7410; SOIC-8_3.9x4.9mm_P1.27mm; LCSC C148144
Q2: IRLML6344; SOT-23; LCSC C53550
R1, R2, R3, R5: 10k; R_0805_2012Metric_Pad1.20x1.40mm_HandSolder; LCSC C17414
R4, R6: 300R; R_0805_2012Metric_Pad1.20x1.40mm_HandSolder; LCSC C17617
SW1: Reset; SW_Push_SPST_NO_Alps_SKRK_handsolder; LCSC C843669
SW2: Flash; SW_Push_SPST_NO_Alps_SKRK_handsolder; LCSC C843669
U1: AMS1117-3.3; SOT-223-3_TabPin2; LCSC C6186
U2: 74LVC1G125; SOT-23-5_HandSoldering; LCSC C23654
U3: ESP32-WROOM-32; LCSC C82899

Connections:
+3V3: C2.1, C3.1, C4.1, C5.1, J1.1, J2.2, R1.1, R2.1, U1.2 (VO), U3.2 (VDD)
+5V: C1.1, J3.2, Q1.1 (S), Q1.2 (S), Q1.3 (S), R3.1, U1.3 (VI), U2.5 (VCC)
ADC: J2.5, U3.4 (SENSOR_VP)
BTN1: J2.3, U3.8 (IO32)
BTN2: J2.4, U3.9 (IO33)
DATA: J3.4, JP1.2 (B), R6.1
DATA_hlv: JP1.1 (A), R6.2, U2.4
DATA_llv: U2.2, U3.24 (IO2)
GND: C1.2, C2.2, C3.2, C4.2, C5.2, C6.2, D1.2 (A), J1.4, J2.1, J3.1, J3.5, Q2.2 (S), R5.2, SW1.1, SW2.1, U1.1 (GND), U2.3 (GND), U3.1 (GND), U3.15 (GND), U3.38 (GND), U3.39 (GND)
unnamed: Q2.1 (G), R4.1, R5.1
unnamed: R1.2, SW1.2, U3.3 (EN)
unnamed: R2.2, SW2.2, U3.25 (IO0)
OE: Q1.4 (G), Q2.3 (D), R3.2, U2.1
RELAY: R4.2, U3.14 (IO12)
RX: J1.3, U3.34 (RXD0/IO3)
TX: J1.2, U3.35 (TXD0/IO1)
WS-Strip_VCC: C6.1, D1.1 (K), J3.3, Q1.5 (D), Q1.6 (D), Q1.7 (D), Q1.8 (D)

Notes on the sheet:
for LLC
Use schottky diode as MOSFET flyback protection.
Bypass jumper for R6, if any problems with data signal.

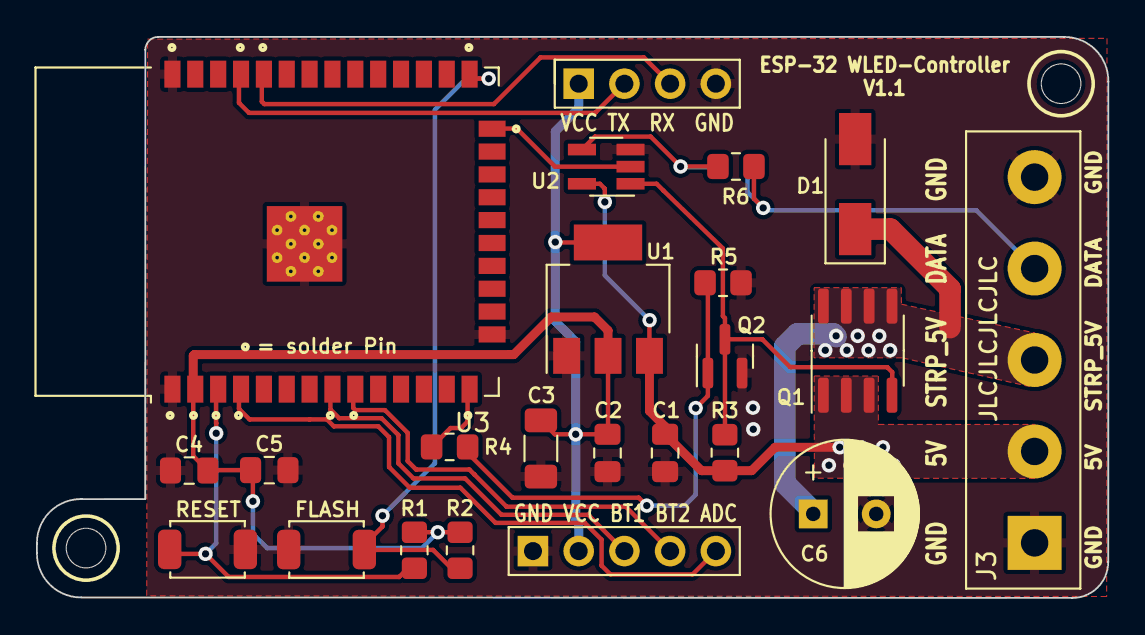
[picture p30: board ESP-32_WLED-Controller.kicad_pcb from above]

Board: 2 copper layers, 59.5 x 31.2 mm, 24 parts (1 on the bottom side), 17 nets.

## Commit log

2023-08-16 Upload gerbers and project folder
2023-08-16 BOM and CPL
    [BOM-ESP-32_WLED-Controller.csv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]
2023-09-17 finalize this repo to PCB V1.1 incl. SR addon
    [ESP-32_WLED-Controller.step, ESP-32_WLED-Controller_Addon.kicad_pcb, ESP-32_WLED-Controller_Addon.kicad_sch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]
2023-10-07 fixed small issues in BOM
    [ESP-32_WLED-Controller_Addon.kicad_pcb, ESP-32_WLED-Controller_Addon.kicad_sch, ESP-32_WLED-Controller_Addon.step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]

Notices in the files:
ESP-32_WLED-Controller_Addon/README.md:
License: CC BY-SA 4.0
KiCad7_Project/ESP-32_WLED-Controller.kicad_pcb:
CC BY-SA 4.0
